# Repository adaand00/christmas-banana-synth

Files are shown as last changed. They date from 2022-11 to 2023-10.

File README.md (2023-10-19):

# Christmas banana synth - Christmas card for 2022

The Christmas banana synth is a stylophone synthesizer with 24 keys and a buzzer for sound. The back features PCB art of a winter landscape. There are also 12 built-in songs available. We used assembly of components by JLCPCB to speed up the process, since we made around 25 boards.

## Video sample (Turn on sound)

https://github.com/adaand00/christmas-banana-synth/assets/45564940/3717fd15-4f71-4382-aa24-0abd6eaa9e98

Credit to Johan (@johanwheeler) for the playing.

## Images
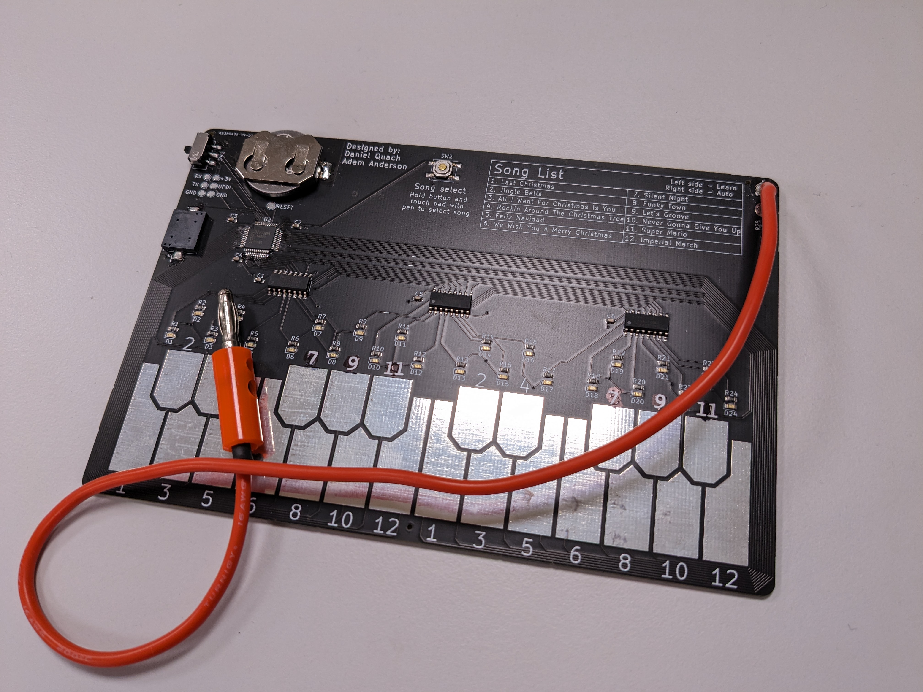
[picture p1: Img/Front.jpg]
Front of PCB

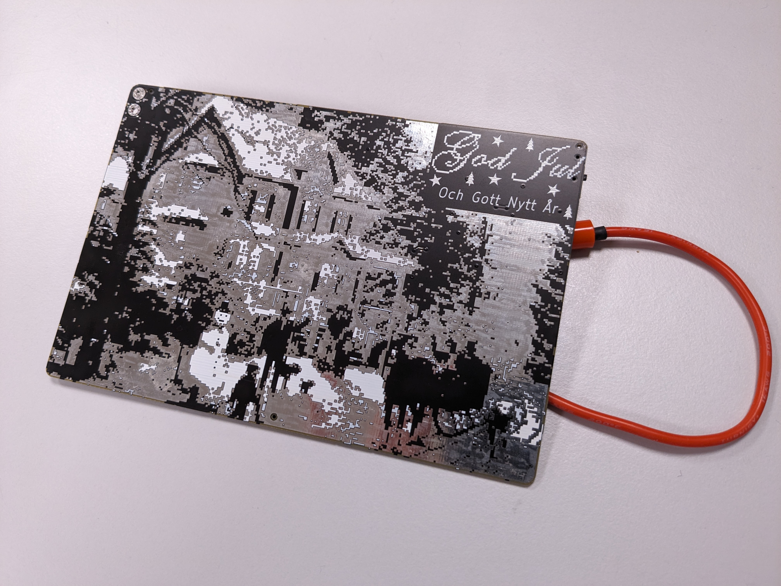
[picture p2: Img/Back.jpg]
Back of PCB


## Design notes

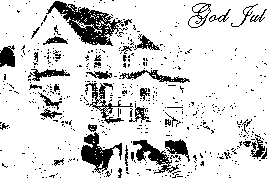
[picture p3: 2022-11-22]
Graphics/Silk.png

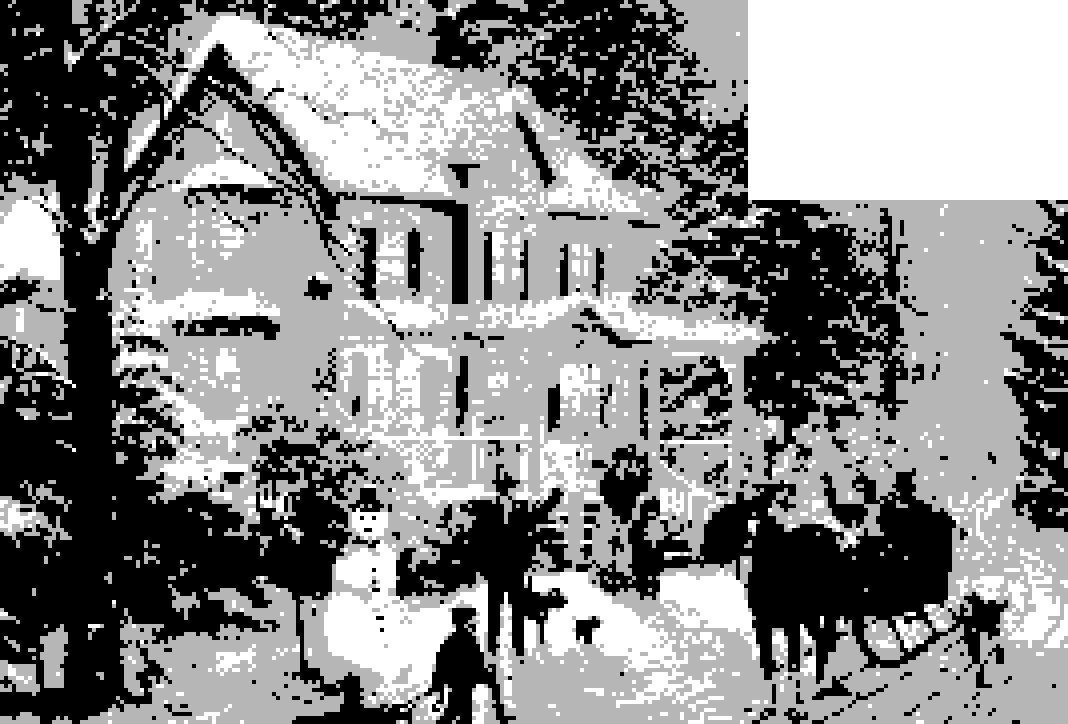
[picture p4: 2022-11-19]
Graphics/ImageProj.png

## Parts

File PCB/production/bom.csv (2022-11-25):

Designator | Footprint | Quantity | Value | LCSC Part #
C1, C3, C4, C5, C6 | C_0603_1608Metric | 5 | 100n | C14663
C2 | C_0603_1608Metric | 1 | 10u | C19702
D1, D10, D11, D12, D13, D14, D15, D16, D17, D18, D19, D2, D20, D21, D22, D23, D24, D3, D4, D5, D6, D7, D8, D9 | LED_0603_1608Metric | 24 | LED | C72043
R1, R10, R11, R12, R13, R14, R15, R16, R17, R18, R19, R2, R20, R21, R22, R23, R24, R25, R3, R4, R5, R6, R7, R8, R9 | R_0603_1608Metric | 25 | 1k | C21190
SW2 | SW_Push_1P1T_NO_CK_KSC6xxJ | 1 | SW_Push | C318884
U1, U3, U4 | SOIC127P600X175-16N | 3 | 74HC595D | C5947

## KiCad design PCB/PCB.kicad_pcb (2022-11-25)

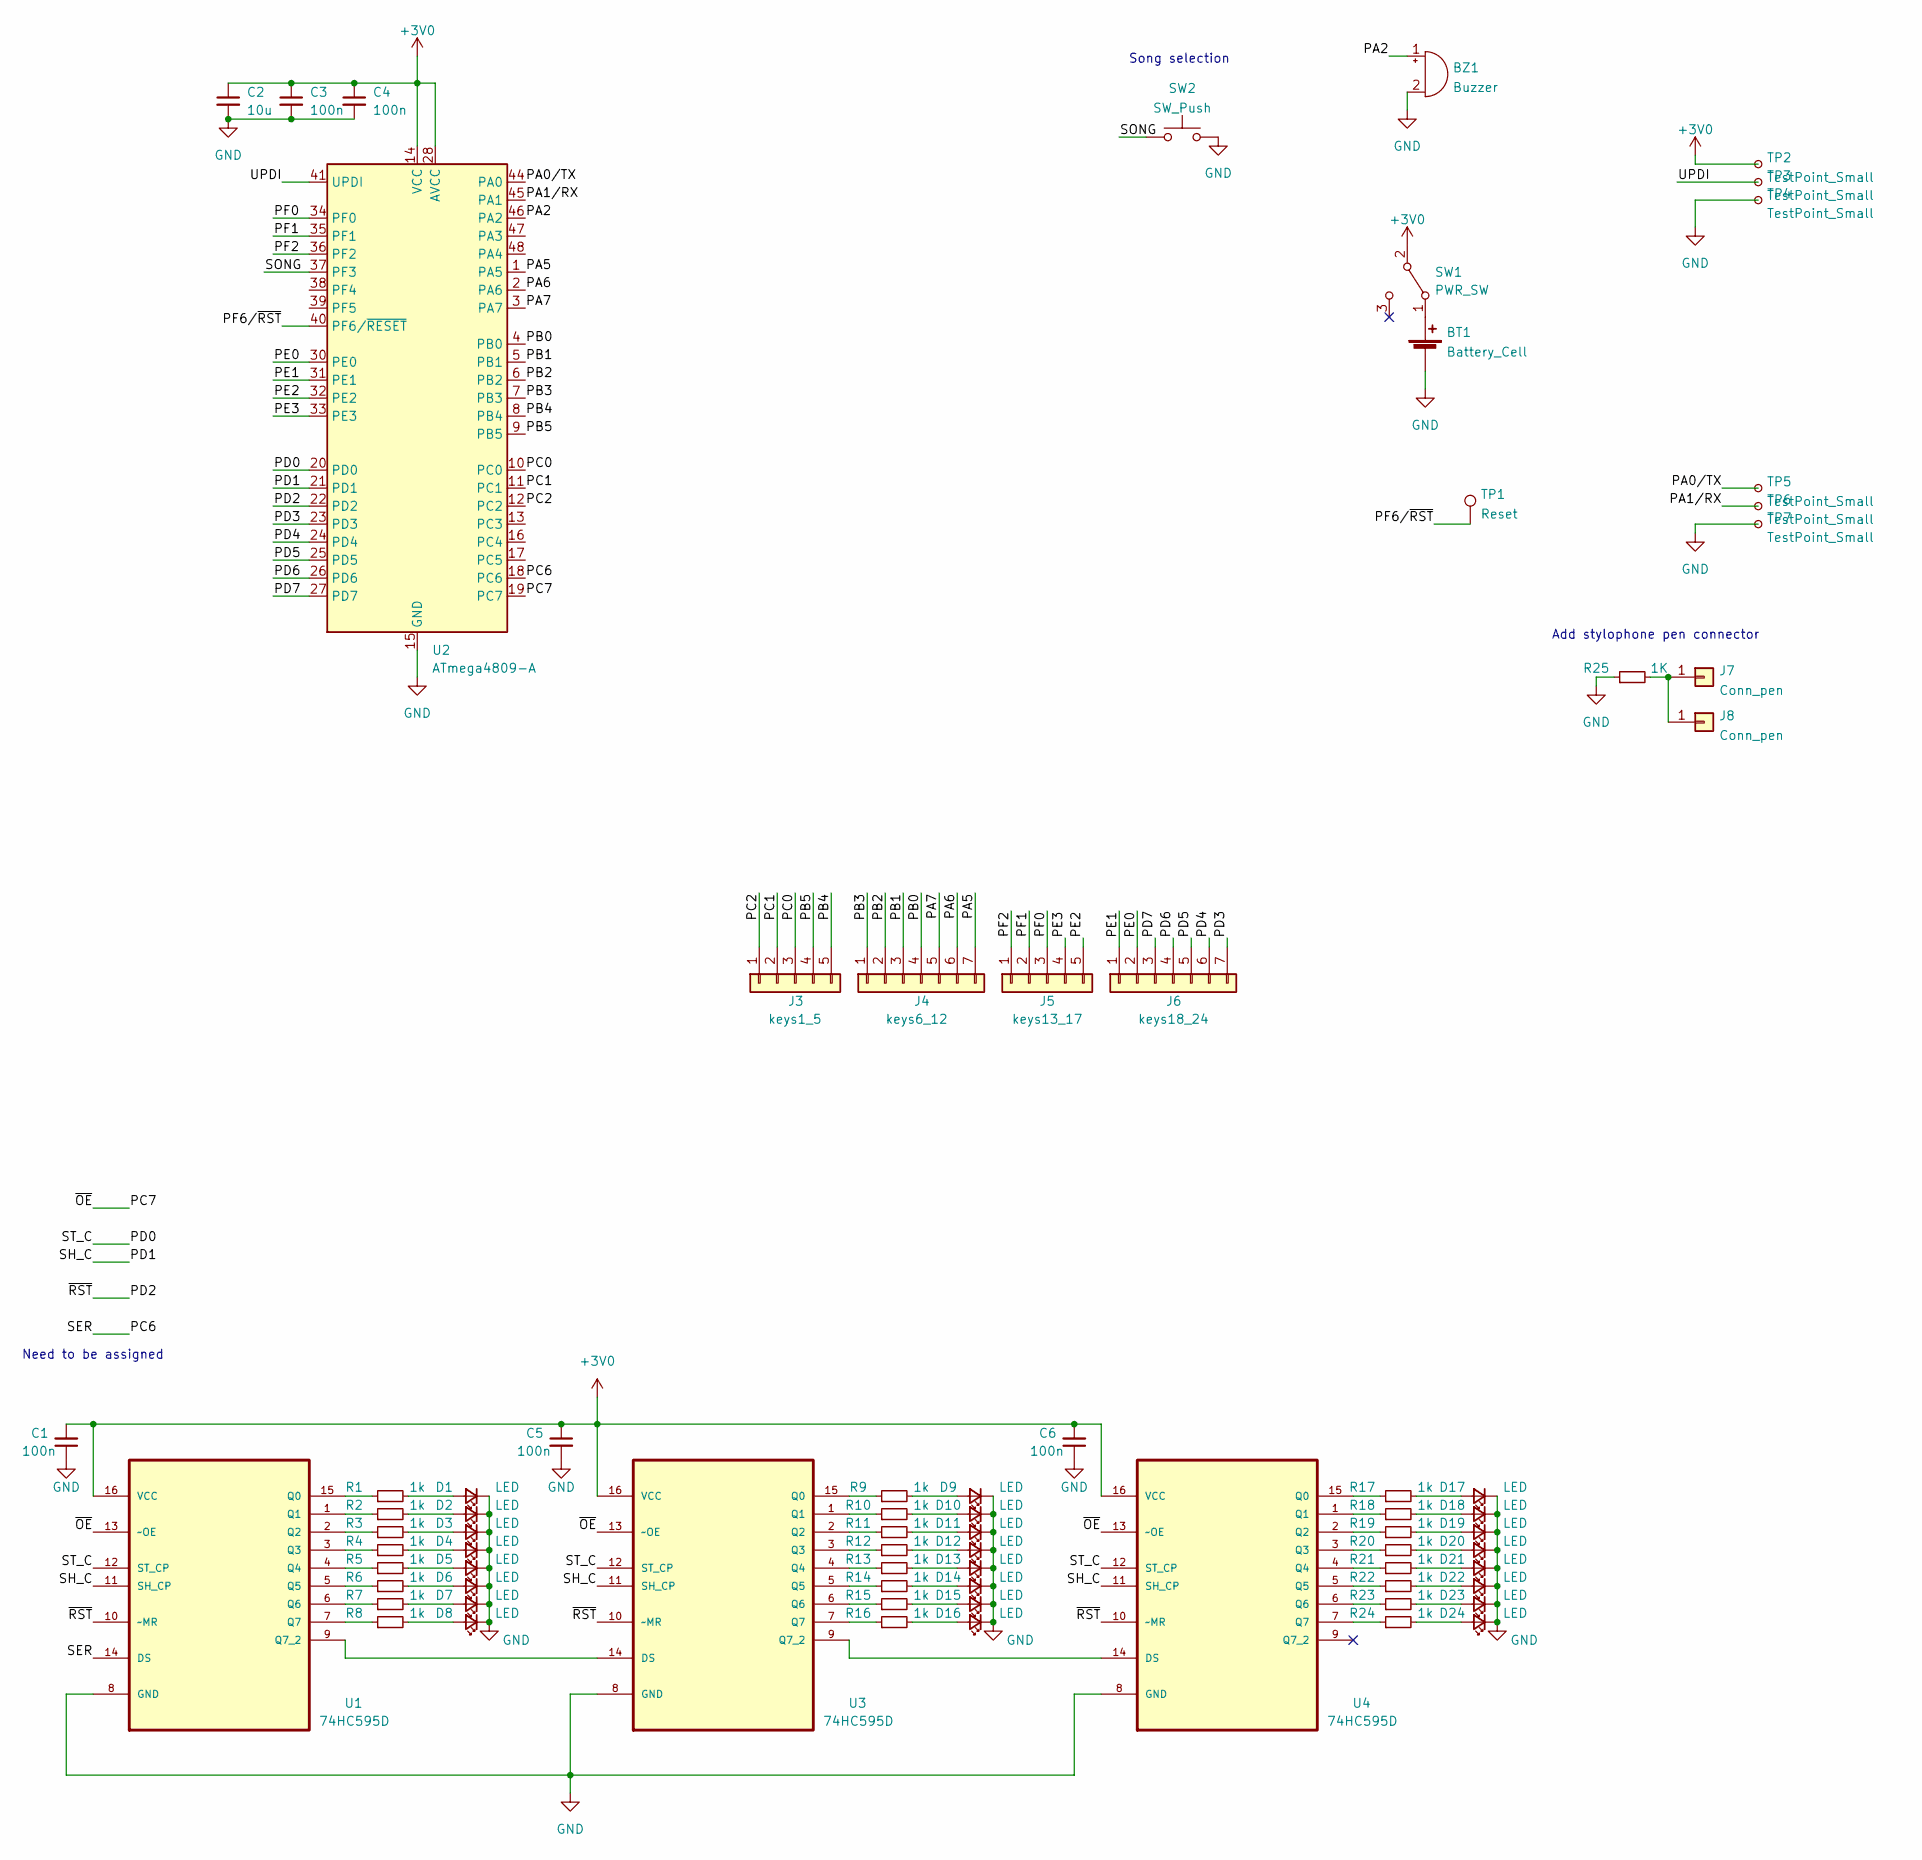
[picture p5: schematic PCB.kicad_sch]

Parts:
BT1: Battery_Cell; BAT-HLD-001
BZ1: Buzzer; CPT-1117-BUZZ
C1, C3, C4, C5, C6: 100n; C_0603_1608Metric
C2: 10u; C_0603_1608Metric
D1, D2, D3, D4, D5, D6, D7, D8, D9, D10, D11, D12, D13, D14, D15, D16, D17, D18, D19, D20, D21, D22, D23, D24: LED; LED_0603_1608Metric
J3: keys1_5; 3w2bv2
J4: keys6_12; 4w3bv2
J5: keys13_17; 3w2bv2
J6: keys18_24; 4w3bv2
J7, J8: Conn_pen; MountingHole_2.2mm_M2_Pad_Via
R1, R2, R3, R4, R5, R6, R7, R8, R9, R10, R11, R12, R13, R14, R15, R16, R17, R18, R19, R20, R21, R22, R23, R24: 1k; R_0603_1608Metric
R25: 1K; R_0603_1608Metric
SW1: PWR_SW; SW_SPDT_CK-JS102011SAQN
SW2: SW_Push; SW_Push_1P1T_NO_CK_KSC6xxJ
TP1: Reset; TestPoint_Pad_D2.0mm
TP2, TP3, TP4, TP5, TP6, TP7: TestPoint_Small; TestPoint_Pad_D1.5mm
U1, U3, U4: 74HC595D; SOIC127P600X175-16N; MPN 74HC595D,118
U2: ATmega4809-A; TQFP-48_7x7mm_P0.5mm

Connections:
+3V0: C1.2, C2.1, C3.1, C4.1, C5.1, C6.2, SW1.2 (B), TP2.1, U1.16 (VCC), U2.14 (VCC), U2.28 (AVCC), U2.42 (VCC), U3.16 (VCC), U4.16 (VCC)
/PA0/TX: TP5.1, U2.44 (PA0)
/PA1/RX: TP6.1, U2.45 (PA1)
/PA2: BZ1.1 (-), U2.46 (PA2)
/PA5: J4.7, U2.1 (PA5)
/PA6: J4.6, U2.2 (PA6)
/PA7: J4.5, U2.3 (PA7)
/PB0: J4.4, U2.4 (PB0)
/PB1: J4.3, U2.5 (PB1)
/PB2: J4.2, U2.6 (PB2)
/PB3: J4.1, U2.7 (PB3)
/PB4: J3.5, U2.8 (PB4)
/PB5: J3.4, U2.9 (PB5)
/PC0: J3.3, U2.10 (PC0)
/PC1: J3.2, U2.11 (PC1)
/PC2: J3.1, U2.12 (PC2)
/PC6: U1.14 (DS), U2.18 (PC6)
/PC7: U1.13 (~OE), U2.19 (PC7), U3.13 (~OE), U4.13 (~OE)
/PD0: U1.12 (ST_CP), U2.20 (PD0), U3.12 (ST_CP), U4.12 (ST_CP)
/PD1: U1.11 (SH_CP), U2.21 (PD1), U3.11 (SH_CP), U4.11 (SH_CP)
/PD2: U1.10 (~MR), U2.22 (PD2), U3.10 (~MR), U4.10 (~MR)
/PD3: J6.7, U2.23 (PD3)
/PD4: J6.6, U2.24 (PD4)
/PD5: J6.5, U2.25 (PD5)
/PD6: J6.4, U2.26 (PD6)
/PD7: J6.3, U2.27 (PD7)
/PE0: J6.2, U2.30 (PE0)
/PE1: J6.1, U2.31 (PE1)
/PE2: J5.5, U2.32 (PE2)
/PE3: J5.4, U2.33 (PE3)
/PF0: J5.3, U2.34 (PF0)
/PF1: J5.2, U2.35 (PF1)
/PF2: J5.1, U2.36 (PF2)
/PF6/~RST: TP1.1, U2.40 (PF6/~RESET)
/SONG: SW2.1, U2.37 (PF3)
/UPDI: TP3.1, U2.41 (UPDI)
GND: BT1.2 (-), BZ1.2 (+), C1.1, C2.2, C3.2, C4.2, C5.2, C6.1, D1.1 (K), D2.1 (K), D3.1 (K), D4.1 (K), D5.1 (K), D6.1 (K), D7.1 (K), D8.1 (K), D9.1 (K), D10.1 (K), D11.1 (K), D12.1 (K), D13.1 (K), D14.1 (K), D15.1 (K), D16.1 (K), D17.1 (K), D18.1 (K), D19.1 (K), D20.1 (K), D21.1 (K), D22.1 (K), D23.1 (K), D24.1 (K), R25.1, SW2.2, TP4.1, TP7.1, U1.8 (GND), U2.15 (GND), U2.29 (GND), U2.43 (GND), U3.8 (GND), U4.8 (GND)
unnamed: BT1.1 (+), SW1.1 (A)
unnamed: D1.2 (A), R1.2
unnamed: D2.2 (A), R2.2
unnamed: D3.2 (A), R3.2
unnamed: D4.2 (A), R4.2
unnamed: D5.2 (A), R5.2
unnamed: D6.2 (A), R6.2
unnamed: D7.2 (A), R7.2
unnamed: D8.2 (A), R8.2
unnamed: D9.2 (A), R9.2
unnamed: D10.2 (A), R10.2
unnamed: D11.2 (A), R11.2
unnamed: D12.2 (A), R12.2
unnamed: D13.2 (A), R13.2
unnamed: D14.2 (A), R14.2
unnamed: D15.2 (A), R15.2
unnamed: D16.2 (A), R16.2
unnamed: D17.2 (A), R17.2
unnamed: D18.2 (A), R18.2
unnamed: D19.2 (A), R19.2
unnamed: D20.2 (A), R20.2
unnamed: D21.2 (A), R21.2
unnamed: D22.2 (A), R22.2
unnamed: D23.2 (A), R23.2
unnamed: D24.2 (A), R24.2
unnamed: J7.1, J8.1, R25.2
unnamed: R1.1, U1.15 (Q0)
unnamed: R2.1, U1.1 (Q1)
unnamed: R3.1, U1.2 (Q2)
unnamed: R4.1, U1.3 (Q3)
unnamed: R5.1, U1.4 (Q4)
unnamed: R6.1, U1.5 (Q5)
unnamed: R7.1, U1.6 (Q6)
unnamed: R8.1, U1.7 (Q7)
unnamed: R9.1, U3.15 (Q0)
unnamed: R10.1, U3.1 (Q1)
unnamed: R11.1, U3.2 (Q2)
unnamed: R12.1, U3.3 (Q3)
unnamed: R13.1, U3.4 (Q4)
unnamed: R14.1, U3.5 (Q5)
unnamed: R15.1, U3.6 (Q6)
unnamed: R16.1, U3.7 (Q7)
unnamed: R17.1, U4.15 (Q0)
unnamed: R18.1, U4.1 (Q1)
unnamed: R19.1, U4.2 (Q2)
unnamed: R20.1, U4.3 (Q3)
unnamed: R21.1, U4.4 (Q4)
unnamed: R22.1, U4.5 (Q5)
unnamed: R23.1, U4.6 (Q6)
unnamed: R24.1, U4.7 (Q7)
unnamed: U1.9 (Q7_2), U3.14 (DS)
unnamed: U3.9 (Q7_2), U4.14 (DS)

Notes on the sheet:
Song selection
Need to be assigned
Add stylophone pen connector

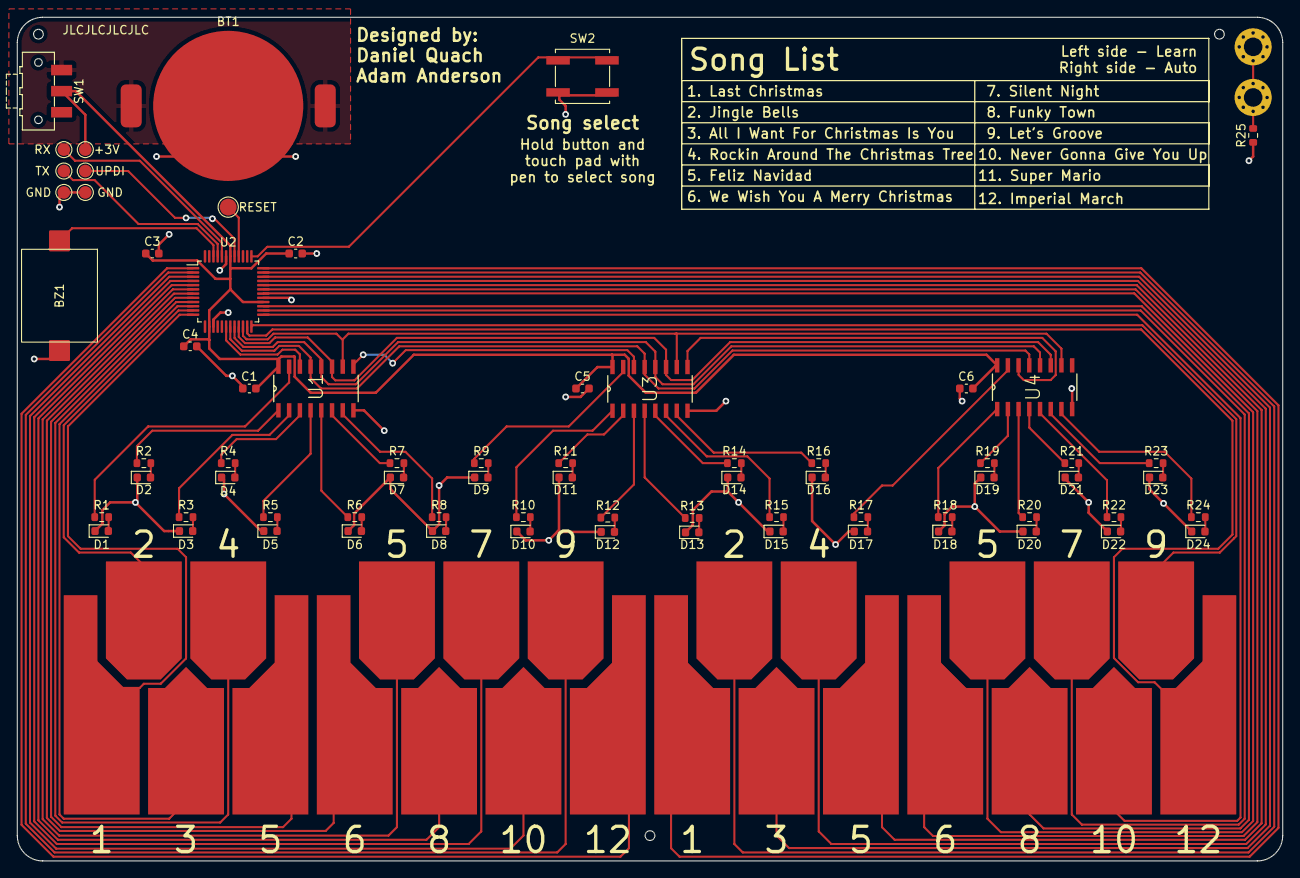
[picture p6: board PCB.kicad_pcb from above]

Board: 2 copper layers, 150.0 x 100.0 mm, 77 parts (1 on the bottom side), 89 nets.

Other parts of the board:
Ref**: Val**; Vectorized

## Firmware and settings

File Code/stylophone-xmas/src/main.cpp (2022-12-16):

#include <Arduino.h>
#include "songs.h"

int keys[] = {
  PIN_PC2, PIN_PC1, PIN_PC0, PIN_PB5, PIN_PB4,
  PIN_PB3, PIN_PB2, PIN_PB1, PIN_PB0, PIN_PA7, PIN_PA6, PIN_PA5,
  PIN_PF2, PIN_PF1, PIN_PF0, PIN_PE3, PIN_PE2,
  PIN_PE1, PIN_PE0, PIN_PD7, PIN_PD6, PIN_PD5, PIN_PD4, PIN_PD3
};

// frequencies from C4 to B5
unsigned int freqz[] = {
  261, 277, 293, 311, 329, 349, 369, 391, 415, 440, 466, 493,
  523, 554, 587, 622, 659, 698, 739, 783, 830, 880, 932, 987
};

uint32_t waitTime = 0;

#define KEY_COUNT 24
#define BUZZER_PIN PIN_PA2
#define BUTTON_PIN PIN_PF3

#define OE_PIN PIN_PC7
#define STORAGE_CLOCK_PIN PIN_PD0
#define SHIFT_CLOCK_PIN PIN_PD1
#define SHIFT_NRST_PIN PIN_PD2
#define DATA_PIN PIN_PC6

void shift_clock() {
  digitalWrite(SHIFT_CLOCK_PIN,   HIGH);
  //digitalWrite probably has enough delay to clock correctly 
  digitalWrite(SHIFT_CLOCK_PIN,   LOW);
}

void LED_show() {
  digitalWrite(STORAGE_CLOCK_PIN, LOW);
  digitalWrite(STORAGE_CLOCK_PIN, HIGH);
}

void LED_clear() {
  digitalWrite(SHIFT_NRST_PIN, LOW);
  digitalWrite(SHIFT_NRST_PIN, HIGH);

  LED_show();
}

void LED_on(int key) {
  LED_clear();
  digitalWrite(DATA_PIN, HIGH);
  shift_clock();
  digitalWrite(DATA_PIN, LOW);

  for (int i = 0; i < key; i++) {
    shift_clock();
  }

  LED_show();
}

int readKeys(){
  for (int i = 0; i < KEY_COUNT; i++) {
    if (digitalRead(keys[i]) == LOW) {
      return i;
    }
  }
  return -1;
}

void playSong(const note_t * song, int length){

  for (int i = 0; i < length; i++) {
    if (song[i].note == 0) {
      noTone(BUZZER_PIN);
      LED_clear();
      delay(song[i].duration);
      continue;
    }

    uint8_t note = song[i].note-1;

    tone(BUZZER_PIN, freqz[note]);
    LED_on(note);
    delay(song[i].duration);
  }

  noTone(BUZZER_PIN);
}

void learnSong(const note_t * song, int length){

  // start learning mode
  for (int i = 0; i < length; i++) {
    if(song[i].note == 0){
      noTone(BUZZER_PIN);
      LED_clear();
      delay(song[i].duration);
      continue;
    }

    uint8_t note = song[i].note-1;

    // turn on LED
    LED_on(note);

    // wait for note to be played
    while (readKeys() != note) { delay(10); }

    //start LED timer
    unsigned long start = millis();

    // wait for duration note to end
    while (millis() - start < song[i].duration)
    {

      if (readKeys() == note) {
        tone(BUZZER_PIN, freqz[note]);
      }else{
        noTone(BUZZER_PIN);
      }

      delay(10);
    }

    LED_clear();

    // wait for note to be released
    while (readKeys() == note) { delay(10); }

    noTone(BUZZER_PIN);

  }
}


void setup() {
  // init keys as input with pullup
  for (int i = 0; i < KEY_COUNT; i++) {
    pinMode(keys[i], INPUT_PULLUP);
  }

  // init buzzer as output
  pinMode(BUZZER_PIN, OUTPUT);

  // init button as input with pullup
  pinMode(BUTTON_PIN, INPUT_PULLUP);

  // init shift register pins as output
  pinMode(OE_PIN, OUTPUT);
  pinMode(STORAGE_CLOCK_PIN, OUTPUT);
  pinMode(SHIFT_CLOCK_PIN, OUTPUT);
  pinMode(SHIFT_NRST_PIN, OUTPUT);
  pinMode(DATA_PIN, OUTPUT);

  // init shift registers
  digitalWrite(STORAGE_CLOCK_PIN, LOW);
  digitalWrite(SHIFT_CLOCK_PIN, LOW);
  LED_clear();
  digitalWrite(OE_PIN, LOW);

  // test all leds and buzzer
  for (int i = 0; i < KEY_COUNT; i++) {
    LED_on(i);
    tone(BUZZER_PIN, freqz[i]);
    delay(60);
  }

  //test buzzer
  tone(BUZZER_PIN, 440, 1000);

}

void loop() {
  // put your main code here, to run repeatedly:

  int key = readKeys();
  int songButton = digitalRead(BUTTON_PIN);

  if (key != -1 && songButton == LOW) {
    if(key<12)
      learnSong(songs[key], song_lengths[key]);
    else
      playSong(songs[key-12], song_lengths[key-12]);

    waitTime = 0;

  } else if (key != -1) {
    LED_on(key);
    tone(BUZZER_PIN, freqz[key]);
    waitTime = 0;
  } else {
    LED_clear();
    noTone(BUZZER_PIN);
  }

  // play snippet of song after 30 seconds
  waitTime += 10;
  if (waitTime > 30000) {
    playSong(songs[4], 10);
    waitTime = 0;
  }

  delay(10);
}

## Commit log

2022-11-19 Start on schematic
    [PCB.kicad_pcb, PCB.kicad_sch]
2022-11-19 schematic almost done
    [PCB.kicad_pcb, PCB.kicad_sch]
2022-11-20 added piano key footprints
2022-11-20 Rough placement of components done
    [PCB.kicad_pcb, PCB.kicad_sch]
2022-11-20 Start routing
    [PCB.kicad_pcb, PCB.kicad_sch]
2022-11-21 Routing of LEDS
    [PCB.kicad_pcb]
2022-11-22 Routing, pin assignments
    [PCB.kicad_pcb, PCB.kicad_sch]
2022-11-24 Final routing
    [PCB.kicad_pcb, PCB.kicad_sch]
2022-11-24 JLC exports
    [bom.csv, designators.csv, positions.csv]
2022-11-25 Finishing touches
    [PCB-B_Cu.gbl, PCB-B_Mask.gbs, PCB-B_Paste.gbp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]
2022-11-25 Finishing touches 2
    [PCB-B_Cu.gbl, PCB-B_Mask.gbs, PCB-B_Paste.gbp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]
2022-12-12 Learning mode working, also inactivity timer
